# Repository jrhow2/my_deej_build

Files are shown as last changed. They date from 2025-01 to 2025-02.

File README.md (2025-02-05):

# jrhow2's Deej Build
## Description

image_jrhow2's_deej

This is a repository to document and share my work on my first Deej build, which includes 1 rotary potentiometer for master volume, 5 slide potentiometers, 6 latching mute 
buttons with LED indicators (one for each slider), and a 12-key macropad. This is primarily based on [miodec's fork](https://github.com/Miodec/deej), which 
adds support for programmable buttons to the original deej project from [omiharel](https://github.com/omriharel/deej).

The main additions I have made to these projects are the use of the [keypad.h](https://github.com/Chris--A/Keypad) library to increase the number of
programmable buttons past what would be achievable using the arduino nano's pins for individual buttons, and the use of latching led as mute buttons/LED indicators. An autohotkey script was used to expand the functionality of the programmable buttons, and a custom PCB was created to more easily add the macropad keyswitches.

In this repository, I've included that CAD files for the enclosure produced in Fusion360, the PCB schematics and gerber files, the customized arduino sketch, and the autohotkey script.

## Wokwi Cicuit design/code simulation
[Wokwi.com](https://wokwi.com) was used for circuit design and siumlation of the Arduino Nano and code. The Wokwi simulation can be found [here](https://wokwi.com/projects/416743878244643841), and the .zip files exported from Wokwi can be found at [deej_jrhow2_wokwi.zip](deej_jrhow2_wokwi.zip).

Note that since wokwi does not include latching buttons and because there was some difficulty with how I soldered my sliders in the final configuration, the code in wokwi does not exactly match the final code in the [provided .ino file](jrhow2s_deej.ino).

## [Mechancal Design](mechanical_design)
### Fusion 360 design files
The enclosure was designed in Fusion 360, and I've provided the [.f3d file](mechanical_design/f360_jrhow2's_deej.f3d).
### 3D printing
Slicing was performed in [Orca Slicer](https://github.com/SoftFever/OrcaSlicer) and the models were printed on a BambuLab P1S with an AMS unit for multi-color printing. I have provided the [Orca Slicer project file](mechanical_design/orca-slicer_jrhow2's_deej.3mf) as well as the [.stls](mechanical_design/STLs) of all of the parts.

To get the faux carbon fiber look on the top surface, I used [this textured plate](https://www.amazon.com/gp/product/B0CP5X3H2Z/ref=ppx_yo_dt_b_search_asin_title?ie=UTF8&psc=1) purchased from Amazon. These kinds of plates work best with slightly increased bed temperature and decreased speed for the first layer or two.

### Part's list
- [5x 60 mm Slide Potentiometers](https://www.amazon.com/dp/B07PNDLKQQ?ref_=ppx_hzsearch_conn_dt_b_fed_asin_title_1)
- [1x Rotary Potentiometer](https://www.amazon.com/dp/B07B64MWRF?ref_=ppx_hzsearch_conn_dt_b_fed_asin_title_2)
- [12x Cherry MX brown keyswitches](https://www.amazon.com/Cherry-MX-RGB-Mechanical-Keyboard/dp/B0CBS5M29R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) (or similar)
- [6x Latching 12mm latching button with LED](https://www.amazon.com/dp/B09YLXBHF6?ref_=ppx_hzsearch_conn_dt_b_fed_asin_title_3&th=1) (2 per order)
- [Assort M2 screws](https://www.amazon.com/dp/B0BXS4SXYC?ref_=ppx_hzsearch_conn_dt_b_fed_asin_title_2) (a few of the holes are a bit shallower than others)
- [Elegoo Arduino Nano](https://www.amazon.com/ELEGOO-Arduino-ATmega328P-Without-Compatible/dp/B0713XK923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)
- Wires, Solder, soldering iron, etc.

### 3D-printed Keycaps
I used [this parametric keycap generator](https://github.com/rsheldiii/KeyV2) with OpenSCAD to make flat keycaps for AMS printing with logos.

## PCB Design
I designed a keypad in KiCad. The PCB is very simple, just connecting the keyswitches together and including some contacts to solder on wires. The pcb files can be found [here](PCB/).

## Arduino Sketch
As mentioned above, my sketch is modified from [miodec's fork](https://github.com/Miodec/deej) by adding support for mute buttons and a keypad. The sketch can be found [here](arduino/jrhow2_deej/).

## Autohotkey script
I used Autohotkey to take the simple keyboard events sent by the arduino sketch and use them to support slightly more complex actions, such as launching apps and a "rage quit" button (just presses alt+f4). In [my config file](config.yaml), I tell Deej to send values for keys that are not commonly used by windows (e.g. "browser home"). Autohotkey then reads these and performs the desired actions. The autohotkey script can be found [here](autohotkey/deej_keys.ahk).

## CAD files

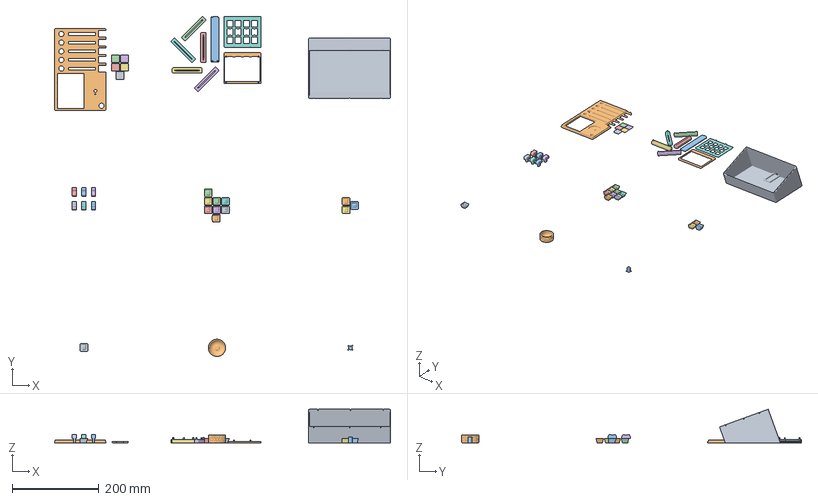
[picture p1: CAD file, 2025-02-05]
mechanical_design/orca-slicer_jrhow2_deej.3mf
777.5 x 786.0 x 77.6 mm
flat_keycap_openscad_20241220.stl x 12
Pot Knob body.step
Pot knob stem.step
Badge_no_tolerance.step x 5
Key Frame.step
PCB Support.step
Badge Support.step
Slider Support.step x 5
Bottom Casing.step
Face Plate.step
Slider.step x 6

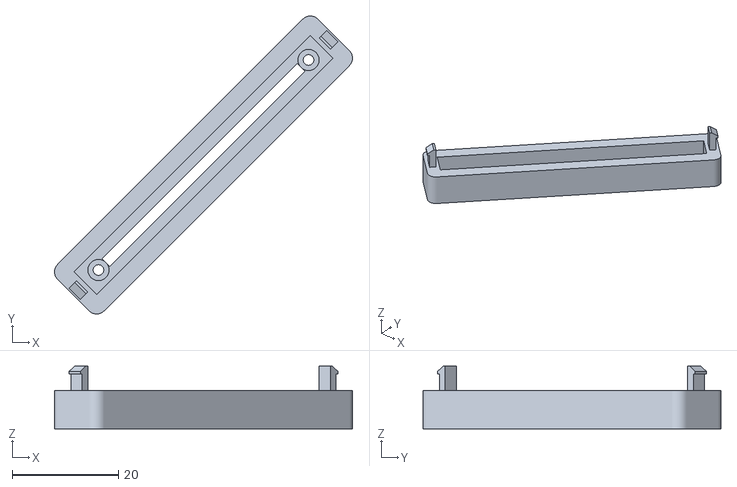
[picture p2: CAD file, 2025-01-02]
mechanical_design/STLs/slider_support.stl
56.2 x 56.2 x 11.9

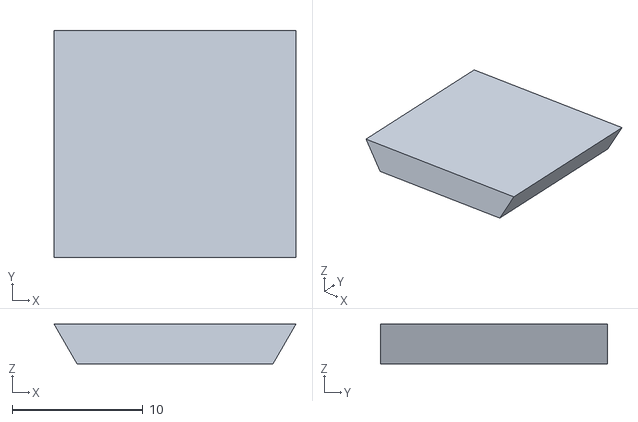
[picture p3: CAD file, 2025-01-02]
mechanical_design/STLs/logo_badge.stl
18.5 x 17.3 x 3.05

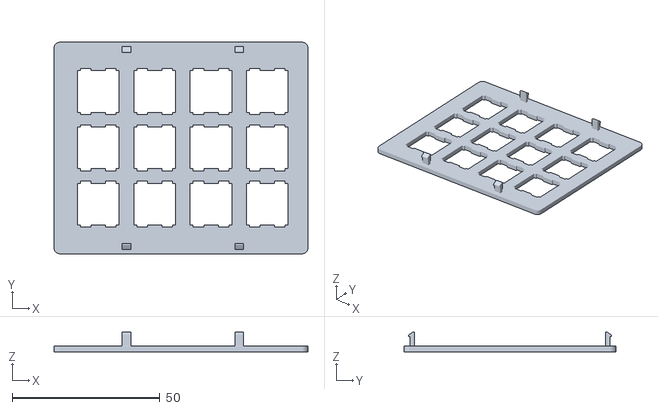
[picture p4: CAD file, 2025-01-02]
mechanical_design/STLs/key_frame.stl
85.9 x 71.6 x 6.65

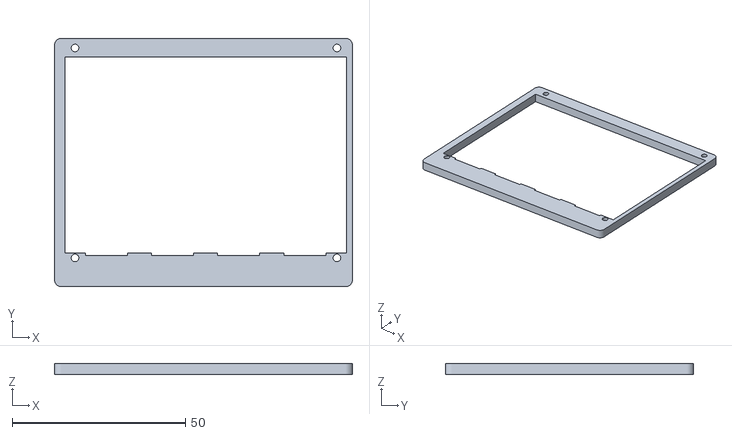
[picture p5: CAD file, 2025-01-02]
mechanical_design/STLs/PCB_support.stl
85.9 x 71.6 x 3.23

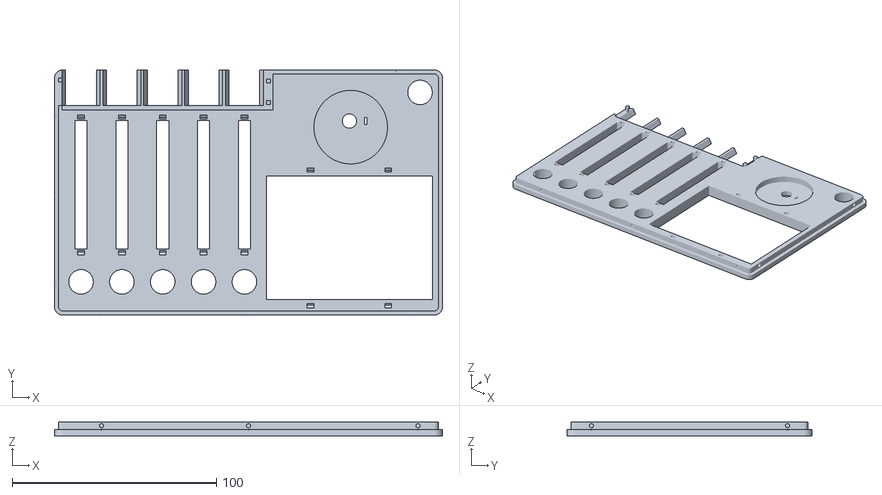
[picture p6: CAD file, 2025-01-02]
mechanical_design/STLs/face_plate.stl
190.0 x 120.0 x 6.88

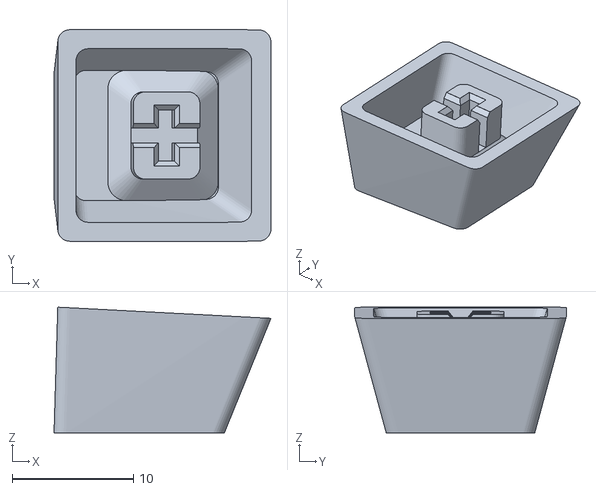
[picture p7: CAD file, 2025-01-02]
mechanical_design/STLs/flat_keycap.stl
17.9 x 17.5 x 10.4

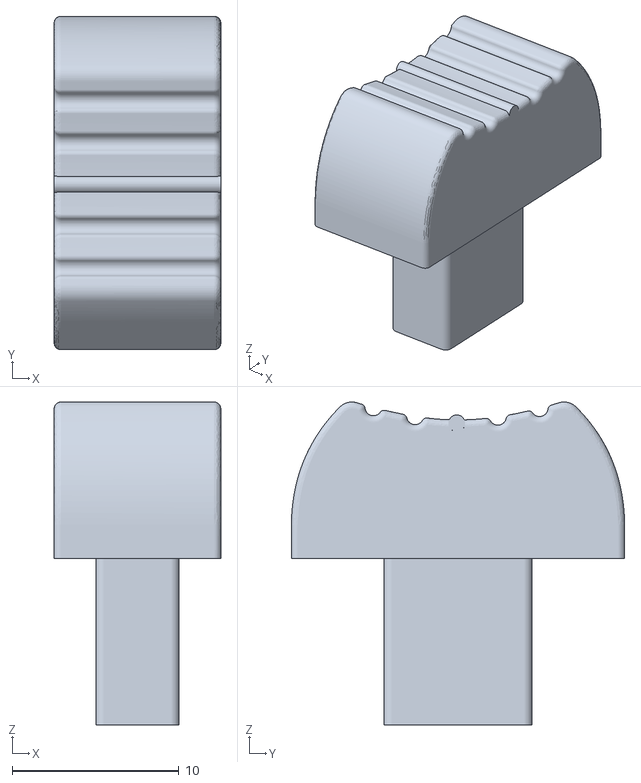
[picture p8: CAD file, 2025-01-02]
mechanical_design/STLs/slider.stl
10.0 x 20.0 x 19.4

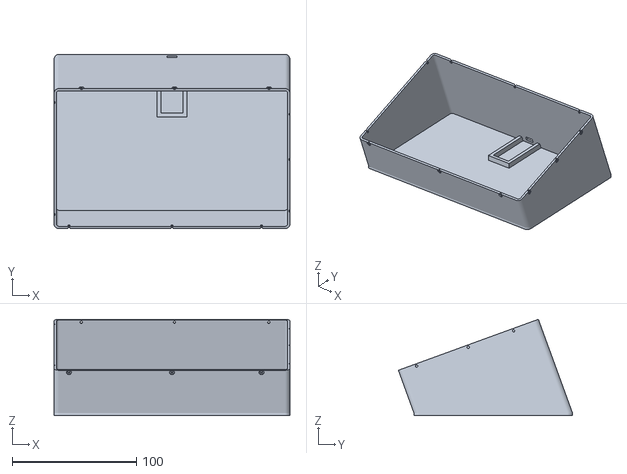
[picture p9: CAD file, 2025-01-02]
mechanical_design/STLs/bottom_casing.stl
190.0 x 140.3 x 77.6

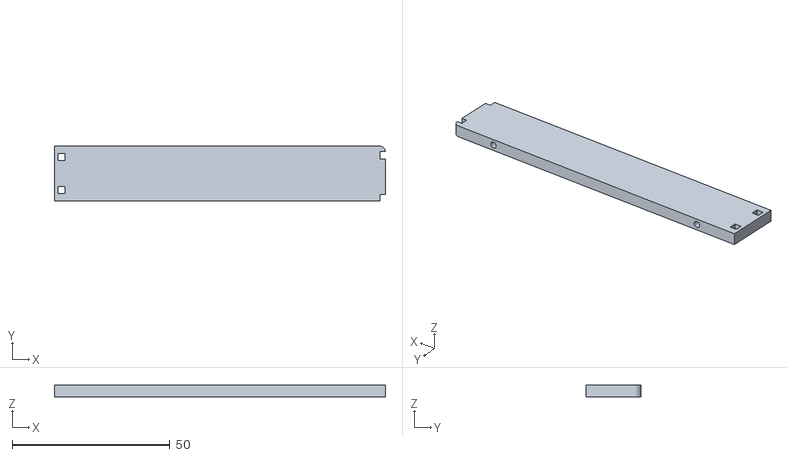
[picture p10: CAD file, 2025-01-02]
mechanical_design/STLs/badge_support.stl
105.0 x 17.5 x 3.68

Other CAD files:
mechanical_design/f360_jrhow2_deej.f3d

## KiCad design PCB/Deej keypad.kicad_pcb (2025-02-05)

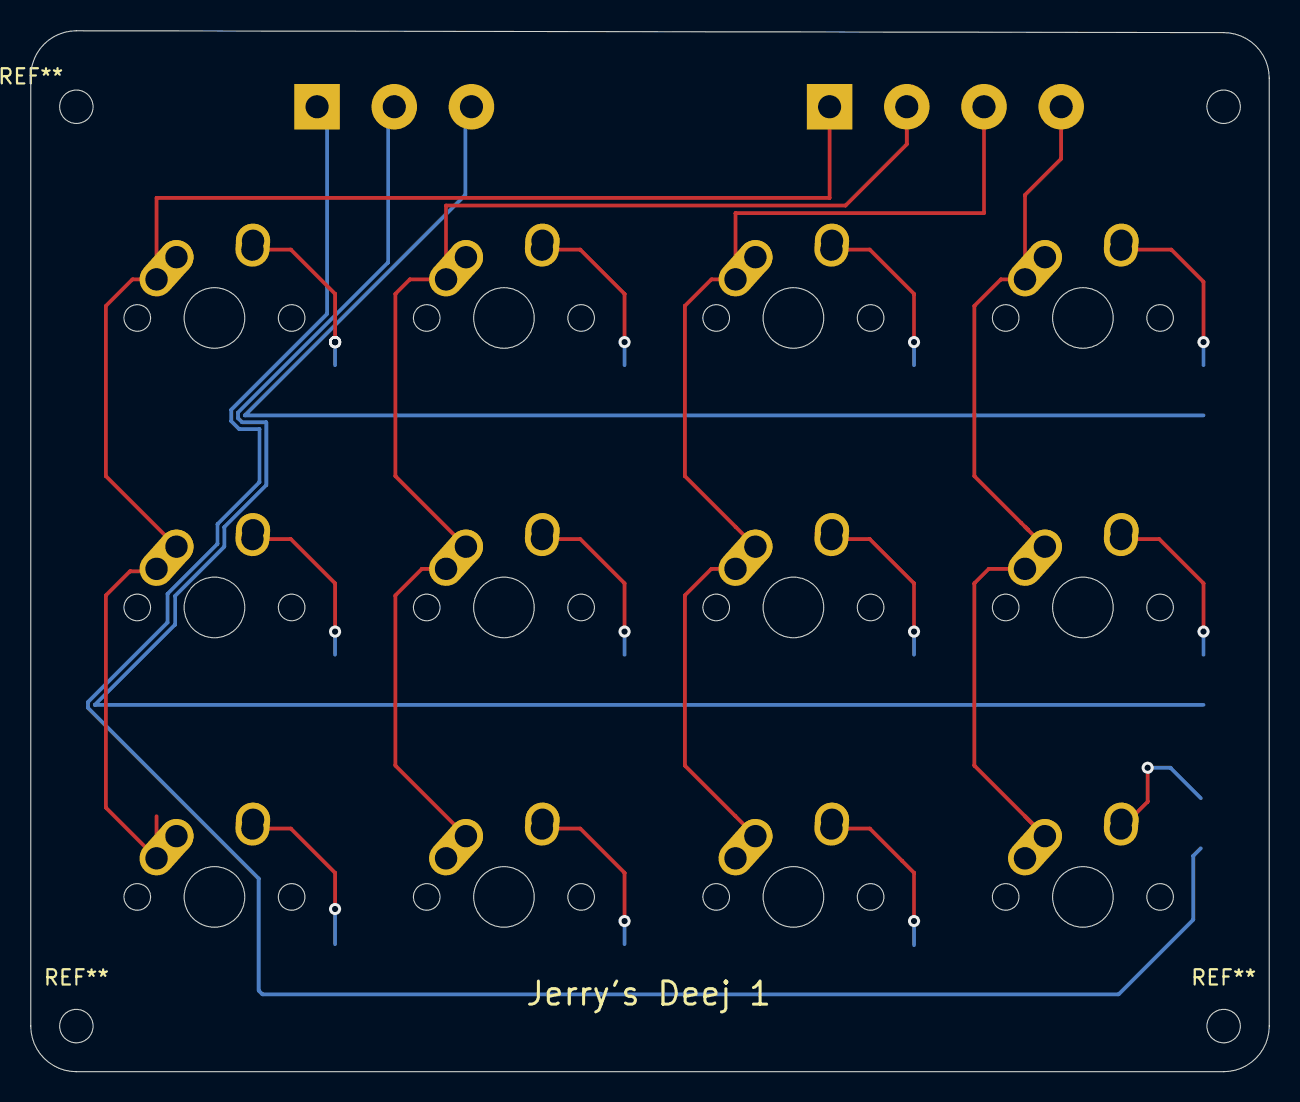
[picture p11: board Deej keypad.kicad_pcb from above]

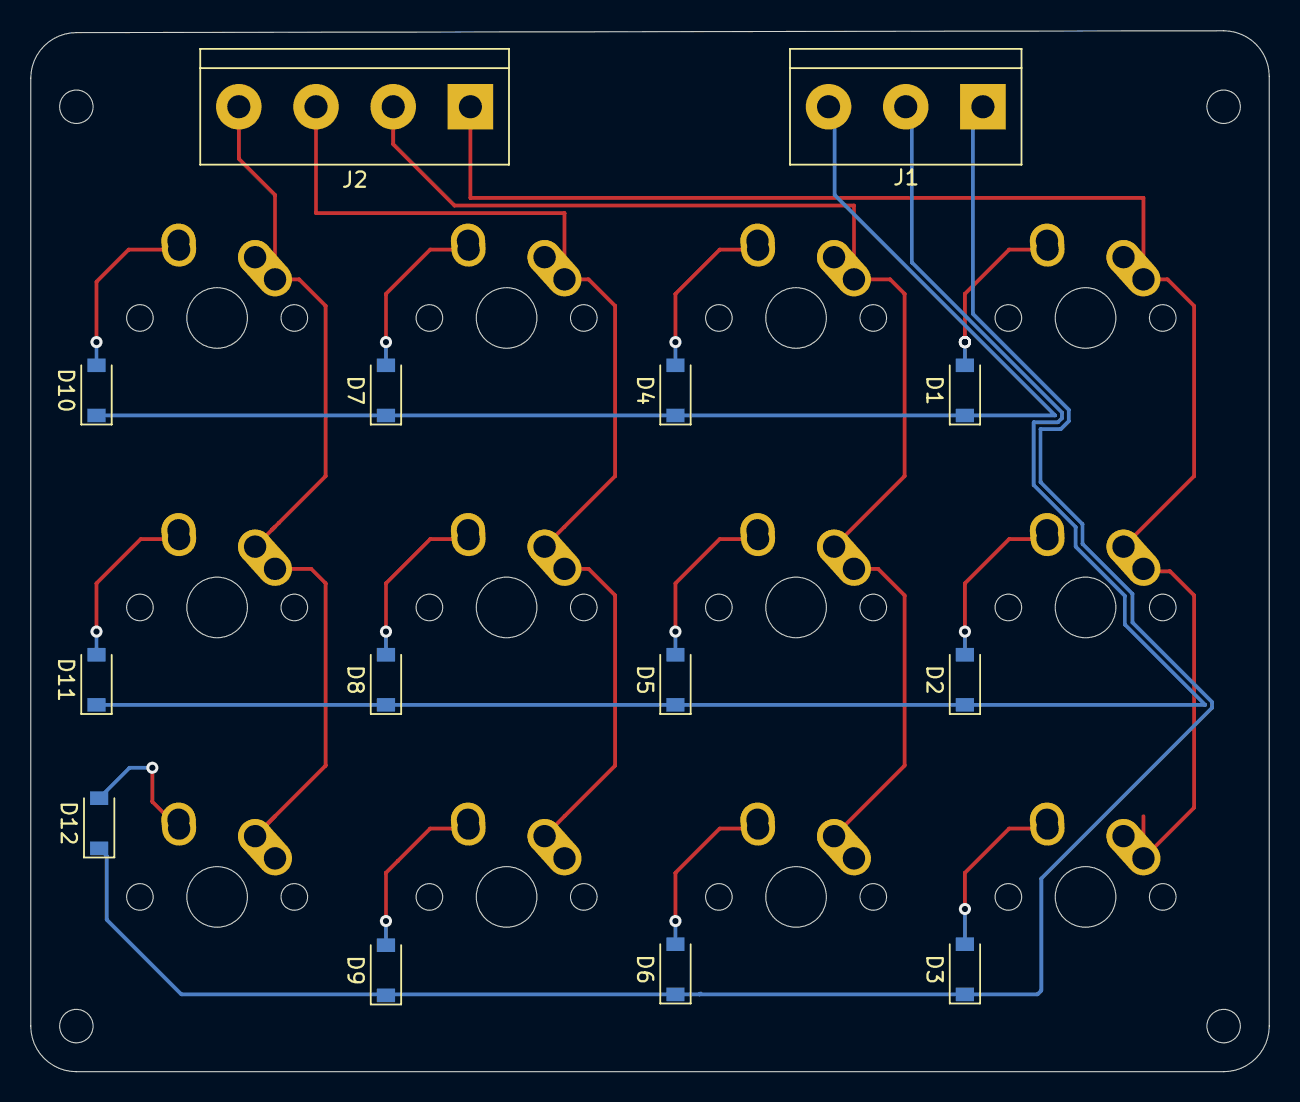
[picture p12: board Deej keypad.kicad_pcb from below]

Board: 2 copper layers, 81.5 x 68.5 mm, 26 parts (14 on the bottom side), 19 nets.

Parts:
D1, D2, D3, D4, D5, D6, D7, D8, D9, D10, D11, D12: D_Small; D_SOD-123
J1: Screw_Terminal_01x03; TerminalBlock_bornier-3_P5.08mm
J2: Screw_Terminal_01x04; TerminalBlock_bornier-4_P5.08mm
MX1, MX2, MX3, MX4, MX5, MX6, MX7, MX8, MX9, MX10, MX11, MX12: MX-NoLED; MX-1U-NoLED

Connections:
COL0: J2.1, MX1.1, MX2.1, MX3.1
COL1: J2.2, MX4.1, MX5.1, MX6.1
COL2: J2.3, MX7.1, MX8.1, MX9.1
COL3: J2.4, MX10.1, MX11.1, MX12.1
unnamed: D1.2, MX1.2
unnamed: D2.2, MX2.2
unnamed: D3.2, MX3.2
unnamed: D4.2, MX4.2
unnamed: D5.2, MX5.2
unnamed: D6.2, MX6.2
unnamed: D7.2, MX7.2
unnamed: D8.2, MX8.2
unnamed: D9.2, MX9.2
unnamed: D10.2, MX10.2
unnamed: D11.2, MX11.2
unnamed: D12.2, MX12.2
ROW0: D3.1, D6.1, D9.1, D12.1, J1.1
ROW1: D2.1, D5.1, D8.1, D11.1, J1.2
ROW2: D1.1, D4.1, D7.1, D10.1, J1.3

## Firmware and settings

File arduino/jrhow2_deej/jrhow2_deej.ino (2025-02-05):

const int NUM_SLIDERS = 6;


const int analogInputs[NUM_SLIDERS] = {A7, A2, A3, A4, A5, A6};
const int NUM_BUTTONS = 12;
const int NUM_MUTES = 6;
int analogSliderValues[NUM_SLIDERS];
int buttonValues[NUM_BUTTONS];
const int mutableSliders[NUM_MUTES] = {1,2,3,4,5,6};
const int muteButtons[NUM_MUTES] = {3,2,A1,4,5,6};
bool muted[NUM_SLIDERS];
int muteValues[NUM_MUTES];

#include <light_CD74HC4067.h>
#include <Keypad.h>


bool firstLoop = true; // Initialize a boolean variable as true
const byte ROWS = 4; //four rows
const byte COLS = 3; //four columns
//define the cymbols on the buttons of the keypads
char keyVals[NUM_BUTTONS] = {'0','1','2','3','4','5','6','7','8','9','A','B'};
char hexaKeys[ROWS][COLS] = {
  {'0','1','2'},
  {'3','4','5'},
  {'6','7','8'},
  {'9','A','B'}
};
byte rowPins[ROWS] = {10,9,8,7}; //connect to the row pinouts of the keypad
byte colPins[COLS] = {11,12,A0}; //connect to the column pinouts of the keypad

//initialize an instance of class NewKeypad
Keypad customKeypad = Keypad( makeKeymap(hexaKeys), rowPins, colPins, ROWS, COLS); 

void setup() {
  for (int i = 0; i < NUM_BUTTONS; i++) {
    buttonValues[i] = 0;
  }
  // pinMode(signal_pin, INPUT_PULLUP); // Set as input for reading through signal pin
  for (int i = 0; i < NUM_SLIDERS; i++) {
    pinMode(analogInputs[i], INPUT);
  }
  for (int i = 0; i < NUM_MUTES; i++) {
    pinMode(muteButtons[i], INPUT_PULLUP);
  }
  
  Serial.begin(9600);
}
static unsigned long lastPressTime = 0;
void loop() {
  updateSliderValues();
  sendSliderValues();
  updateButtonValues();

   // Actually send data (all the time)
  // printSliderValues(); // For debug
  //delay(10);
}

void updateButtonValues() {
  for (int i = 0; i < NUM_BUTTONS; i++) {
   buttonValues[i] = 0;
   }

  char customKey = customKeypad.getKey();
  
  for (int i=0; i<NUM_BUTTONS;i++) {
    if (customKey == keyVals[i] && buttonValues[i] == 0){
      buttonValues[i] = 1;
      lastPressTime = millis();
    }
  }
}

void updateSliderValues() {
  for (int i = 0; i < NUM_SLIDERS; i++) {
    // analogSliderValues[i] = analogRead(analogInputs[i]);
    if (i == 0) {
      // analogSliderValues[i] = analogRead(analogInputs[i]);
     analogSliderValues[i] = (1023 - analogRead(analogInputs[i]));
    }
    else {
     analogSliderValues[i] = analogRead(analogInputs[i]);
     analogSliderValues[i] = analogRead(analogInputs[i]);
    }
    
  }

  for (int i = 0; i < NUM_MUTES; i++) {
    muteValues[i] = digitalRead(muteButtons[i]);
    // String printedString = String((int)muteValues[i]);  
    // Serial.write(printedString.c_str());
    if (muteValues[i] == 0) {
       muted[mutableSliders[i]-1] = true;
      //  String printedString = String((int)mutableSliders[i]);
      //  Serial.write(printedString.c_str());

    }
    else if (muteValues[i] == 1) {
      muted[mutableSliders[i]-1] = false;

    }
  }
  
  for (int i = 0; i < NUM_SLIDERS; i++) {
    // String printedString = String((int)muted[i]);
    // Serial.write(printedString.c_str());
    if (muted[i]) {
      analogSliderValues[i] = 0;
    }
    
  }

}

void sendSliderValues() {
  String builtString = String("");

  for (int i = 0; i < NUM_SLIDERS; i++) {
    builtString += "s";
    builtString += String((int)analogSliderValues[i]);

    if (i < NUM_SLIDERS - 1) {
      builtString += String("|");
    }
  }

  if(NUM_BUTTONS > 0){
    builtString += String("|");
  }


  for (int i = 0; i < NUM_BUTTONS; i++) {
    builtString += "b";
    builtString += String((int)buttonValues[i]);

    if (i < NUM_BUTTONS - 1) {
      builtString += String("|");
    }
  }

  Serial.println(builtString);
}

void printSliderValues() {
  for (int i = 0; i < NUM_SLIDERS; i++) {
    String printedString = String("Slider #") + String(i + 1) + String(": ") + String(analogSliderValues[i]) + String(" mV");
    // String printedString = String(analogSliderValues[i]);

    Serial.write(printedString.c_str());

    if (i < NUM_SLIDERS - 1) {
      Serial.write(" | ");
    } else {
      Serial.write("\n");
    }
  }
}

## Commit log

2024-12-09 Initializing with KiCad files
    [ai03-pcb-guide.kicad_pcb, ai03-pcb-guide.sch]
2024-12-09 Switched to older version for compatibility with guide
    [ai03_pcb_guide.kicad_pcb, ai03_pcb_guide.sch]
2024-12-09 Added libraries to pcb editor
2024-12-09 Started designing PCB for deej keypad
    [Deej keypad.kicad_pcb, Deej keypad.sch, ai03_pcb_guide.kicad_pcb]
2024-12-09 saving changes
    [Deej keypad.sch]
2025-01-01 Uploaded main files for running deej
    Uploaded config.yaml, autohotkey script, and arduino sketch.
2025-01-02 Rename Jrhow2's Deej.f3d to Mechanical Design/Jrhow2's Deej.f3d
    [Jrhow2's Deej.f3d]
2025-01-02 Update and rename Jrhow2's Deej.f3d to jrhow2's_deej.f3d
    [jrhow2's_deej.f3d]
2025-01-02 Rename Deej top face 20241220.3mf to jrhow2's deej.3mf
    [Deej top face 20241220.3mf, jrhow2's deej.3mf]
2025-01-02 Rename mechanical_design/Key Frame.step.stl to mechanical_design/STLs/key_frame.stl
    [key_frame.stl]
2025-01-02 Update and rename jrhow2's deej.3mf to jrhow2's_deej.3mf
    [jrhow2's_deej.3mf]
2025-01-02 Update and rename jrhow2's_deej.3mf to orca-slicer_jrhow2's_deej.3mf
    [orca-slicer_jrhow2's_deej.3mf]
2025-01-02 Update and rename jrhow2's_deej.f3d to f360_jrhow2's_deej.f3d
    [f360_jrhow2's_deej.f3d]
2025-02-05 replace the broken f3d file
    [f360_jrhow2's_deej.f3d, f360_jrhow2_deej.f3d]
2025-02-05 fixed the broke orca slicer .3mf
    [orca-slicer_jrhow2_deej.3mf]
2025-02-05 deleted old .3mf file
    [orca-slicer_jrhow2's_deej.3mf]
2025-02-05 Update README.md
    Added link for screws I used
2025-02-05 Added PCB files for KiCad
    [Deej keypad-B_Cu.gbl, Deej keypad-B_Mask.gbs, Deej keypad-B_SilkS.gbo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]
2025-02-05 Update README.md
    Added PCB details to README
2025-02-05 added arduino sketch and autohotkey file
2025-02-05 Update README.md
    Added arduino and autohotkey details to README.
2025-02-05 Update README.md
    fixed link to arduino sketch.
